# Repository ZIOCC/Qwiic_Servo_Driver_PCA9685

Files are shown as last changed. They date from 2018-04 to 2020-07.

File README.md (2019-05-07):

# Qwiic 16 Servo Driver (PCA9685)

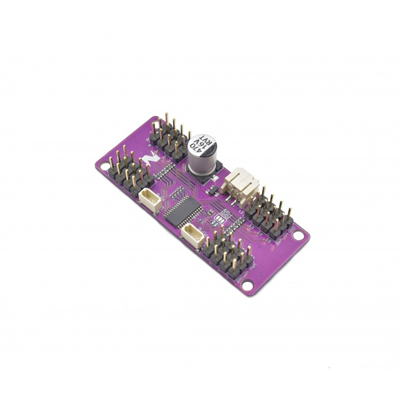
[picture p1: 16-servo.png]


> This product can be available for purchase [here](https://www.smart-prototyping.com/Zio-16-Servo-Controller.html).

#### Description

With the Zio 16-Channel 12 bit PWM controller, using the PCA9685 from NXP Semiconductors, you can control up to 16 servos or other PWM-controllable components using I2C.

Each output can be off or on (no PWM control), or set any channel to its own PWM frequency and duty cycle. The PCA9685 operates with a supply voltage range of 2.3v to 5.5v and both the inputs and outputs are 5.5v tolerant. Servos can be connected directly to output pins (up to 25 mA, 5.5v) or controlled with external drivers for more power-hungry applications. 

The board comes equipped with two Qwiic connectors to enable easy daisy-chaining. Need even more channels to control something like a hexapod robot? Quickly and easily connect another servo controller with the additional Qwiic connector and 6 solder-jumper configurable address bits. That means you can have up to 62 of these boards operating on the same I2C bus. You can also configure the boards to recognize group addresses, so that multiple boards can be controlled in parallel with a single command.

This is a derivative of Adafruit’s 16-Channel 12-bit PWM/Servo Driver - I2C interface - PCA9685, with the main difference being the addition of the Qwiic connectors. If you want to make Qwiic a regular part of your hardware hacking/making toolkit (we can’t image why you wouldn’t), this is the Servo Driver for you.

#### Specification

* 62 possible I2C addresses
* Weight: 8.0g (0.278oz)
* Dimension: 59.5x25.2 mm
* IC: PCA9685
* I2C address: 0x40-0x7F (default: 0x40)

#### Links

* [PCA9685 datasheet](https://www.smart-prototyping.com/image/data/NOA-RnD/101896%2016%20Servo%20Controller/PCA9685.pdf)
* [Adafruit PWM Servo Driver Library](https://github.com/adafruit/Adafruit-PWM-Servo-Driver-Library)
* [Example Code](https://www.smart-prototyping.com/image/data/NOA-RnD/101896%2016%20Servo%20Controller/2_servos.ino0)
* [Eagle files](https://github.com/ZIOCC/Qwiic_Servo_Driver_PCA9685)

Connections for Example Code, connecting two servos to the servo driver board. 



> ###### About Zio
> Zio is a new line of open sourced, compact, and grid layout boards, fully integrated for Arduino and Qwiic ecosystem. Designed ideally for wearables, robotics, small-space limitations or other on the go projects. Check out other awesome Zio products [here](https://www.smart-prototyping.com/Zio).

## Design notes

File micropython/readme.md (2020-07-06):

#### Usage
This driver board can control up to 16 servos via I2C. It is highly recommended to use extenal power source for the driver board, the I2C don't have enough current to drive servos.  

#### Demo code:
In this demo I connected the servo to the channel number 11, so the ser.position() first arguement is 11. 1000 us = 1ms
```  
from machine import I2C, Pin
import servo

i2c = I2C(2)
ser = servo.Servos(i2c)
while True:

    ser.position(11,us=1500) # 11 is your servo channel, us is servo position, usually the value is from 0.5ms to 2.5ms
    pyb.delay(1000)
    ser.position(11, us=2000)
    pyb.delay(1000)

```  

#### Note:
You will need to copy pca9685.py and servo.py file to your micropython board.
servo position and us relations(normally):
us value | servo position |
 ---- | -----
500 us  | 0 degree
1000 us | 45 degree
1500 us | 90 degree
2000 us | 135 degree
2500 us | 180 degree

#### Product link:
[Zio 16 Servo Controller (Qwiic)](https://www.smart-prototyping.com/Zio-16-Servo-Controller.html)

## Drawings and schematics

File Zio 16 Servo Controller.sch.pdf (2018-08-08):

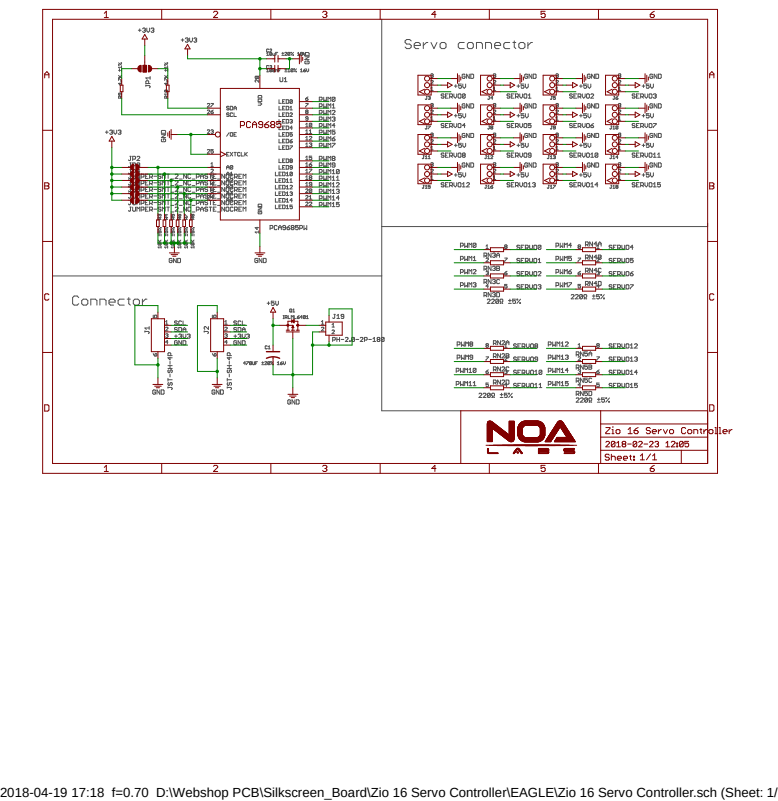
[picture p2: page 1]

2018-04-19 17:18 f=0.70 D:\Webshop PCB\Silkscreen_Board\Zio 16 Servo Controller\EAGLE\Zio 16 Servo Controller.sch (Sheet: 1/1)

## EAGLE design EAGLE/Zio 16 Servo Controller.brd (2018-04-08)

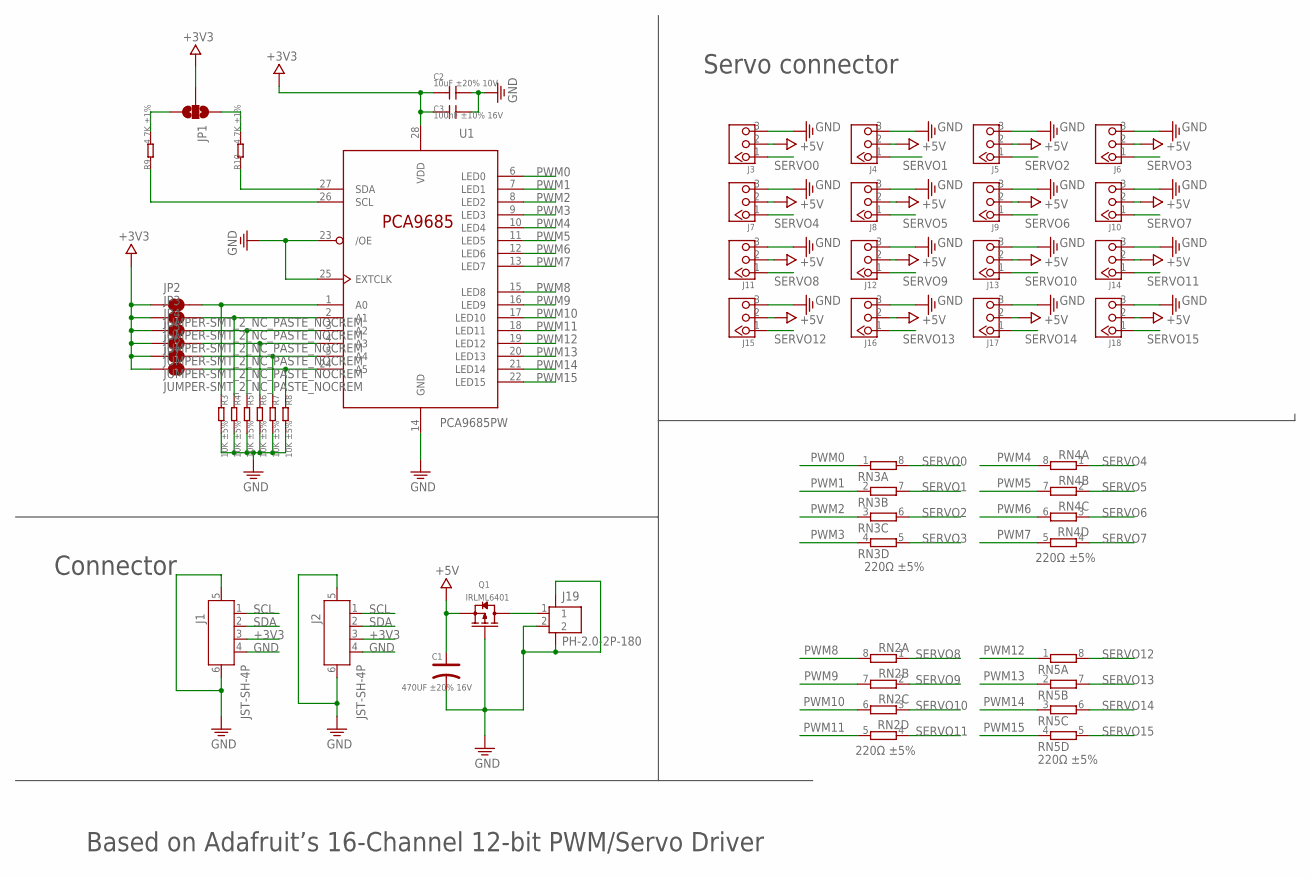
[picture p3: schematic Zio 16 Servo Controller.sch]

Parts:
C1: 470UF ±20% 16V; ELECTRO-SMD-E-7.8MM
C2: 10uF ±20% 10V; 0402
C3: 100nF ±10% 16V; 0402
J1, J2: JST-SH-4P; JST-SH-4P-90
J3, J4, J5, J6, J7, J8, J9, J10, J11, J12, J13, J14, J15, J16, J17, J18: HEADER-3P-2.54; 3P-2.54
J19: PH-2.0-2P-180; PH2.0_2P_180
JP1: JUMPER-SMT_3_2-NC_PASTE_NOCREM; SMT-JUMPER_3_2-NC_PASTE_SILK_NOCREM
JP2, JP3, JP4, JP5, JP6, JP7: JUMPER-SMT_2_NC_PASTE_NOCREM; SMT-JUMPER_2_NC_PASTE_SILK_NOCREM
Q1: IRLML6401; SOT23
R3, R4, R5, R6, R7, R8: 10K ±5%; 0402
R9, R10: 4.7K ±1%; 0402
RN2, RN3, RN4, RN5: 220Ω ±5%; RESISTOR-DIL_0603-ARV
U1: PCA9685PW; TSSOP28

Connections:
+3V3: C2.1, C3.1, J1.3, J2.3, JP1.2, JP2.1, JP3.1, JP4.1, JP5.1, JP6.1, JP7.1, U1.28 (VDD)
+5V: C1.+, J3.2, J4.2, J5.2, J6.2, J7.2, J8.2, J9.2, J10.2, J11.2, J12.2, J13.2, J14.2, J15.2, J16.2, J17.2, J18.2, Q1.2 (S)
GND: C1.-, C2.2, C3.2, J1.4, J1.5, J1.6, J2.4, J2.5, J2.6, J3.3, J4.3, J5.3, J6.3, J7.3, J8.3, J9.3, J10.3, J11.3, J12.3, J13.3, J14.3, J15.3, J16.3, J17.3, J18.3, J19.2, J19.3, J19.4, Q1.1 (G), R3.2, R4.2, R5.2, R6.2, R7.2, R8.2, U1.14 (GND), U1.23 (/OE), U1.25 (EXTCLK)
unnamed: JP2.2, R3.1, U1.1 (A0)
unnamed: JP3.2, R4.1, U1.2 (A1)
unnamed: JP4.2, R5.1, U1.3 (A2)
unnamed: JP5.2, R6.1, U1.4 (A3)
unnamed: JP6.2, R7.1, U1.5 (A4)
unnamed: JP7.2, R8.1, U1.24 (A5)
unnamed: J19.1, Q1.3 (D)
unnamed: JP1.3, R9.2
unnamed: JP1.1, R10.2
PWM0: RN3.1, U1.6 (LED0)
PWM1: RN3.2 (1), U1.7 (LED1)
PWM2: RN3.3 (1), U1.8 (LED2)
PWM3: RN3.4 (1), U1.9 (LED3)
PWM4: RN4.8 (2), U1.10 (LED4)
PWM5: RN4.7 (2), U1.11 (LED5)
PWM6: RN4.6 (2), U1.12 (LED6)
PWM7: RN4.5 (2), U1.13 (LED7)
PWM8: RN2.8 (2), U1.15 (LED8)
PWM9: RN2.7 (2), U1.16 (LED9)
PWM10: RN2.6 (2), U1.17 (LED10)
PWM11: RN2.5 (2), U1.18 (LED11)
PWM12: RN5.1, U1.19 (LED12)
PWM13: RN5.2 (1), U1.20 (LED13)
PWM14: RN5.3 (1), U1.21 (LED14)
PWM15: RN5.4 (1), U1.22 (LED15)
SCL: J1.1, J2.1, R9.1, U1.26 (SCL)
SDA: J1.2, J2.2, R10.1, U1.27 (SDA)
SERVO0: J3.1, RN3.8 (2)
SERVO1: J4.1, RN3.7 (2)
SERVO2: J5.1, RN3.6 (2)
SERVO3: J6.1, RN3.5 (2)
SERVO4: J7.1, RN4.1
SERVO5: J8.1, RN4.2 (1)
SERVO6: J9.1, RN4.3 (1)
SERVO7: J10.1, RN4.4 (1)
SERVO8: J11.1, RN2.1
SERVO9: J12.1, RN2.2 (1)
SERVO10: J13.1, RN2.3 (1)
SERVO11: J14.1, RN2.4 (1)
SERVO12: J15.1, RN5.8 (2)
SERVO13: J16.1, RN5.7 (2)
SERVO14: J17.1, RN5.6 (2)
SERVO15: J18.1, RN5.5 (2)

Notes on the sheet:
Servo connector
Connector
Based on Adafruit’s 16-Channel 12-bit PWM/Servo Driver

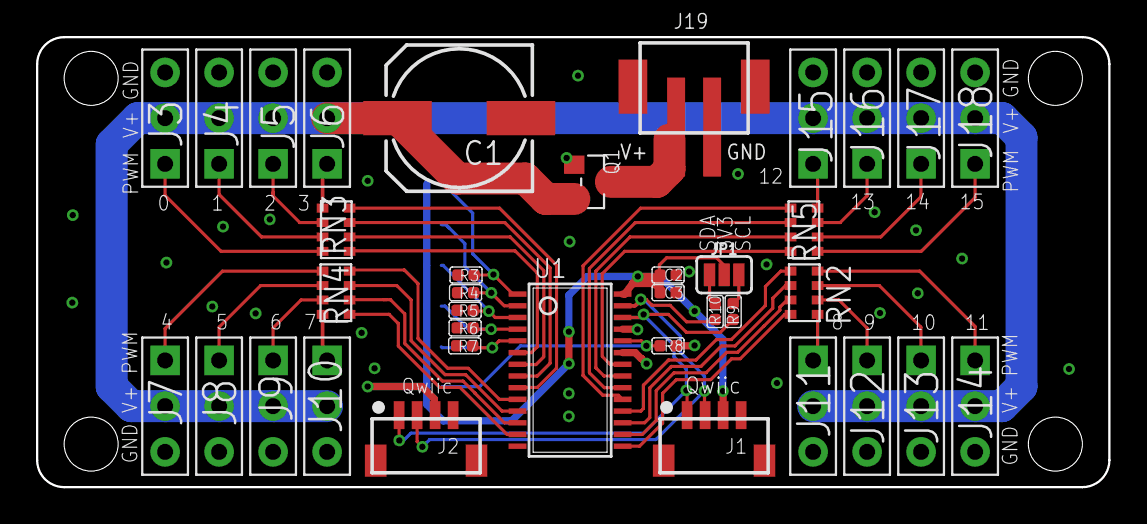
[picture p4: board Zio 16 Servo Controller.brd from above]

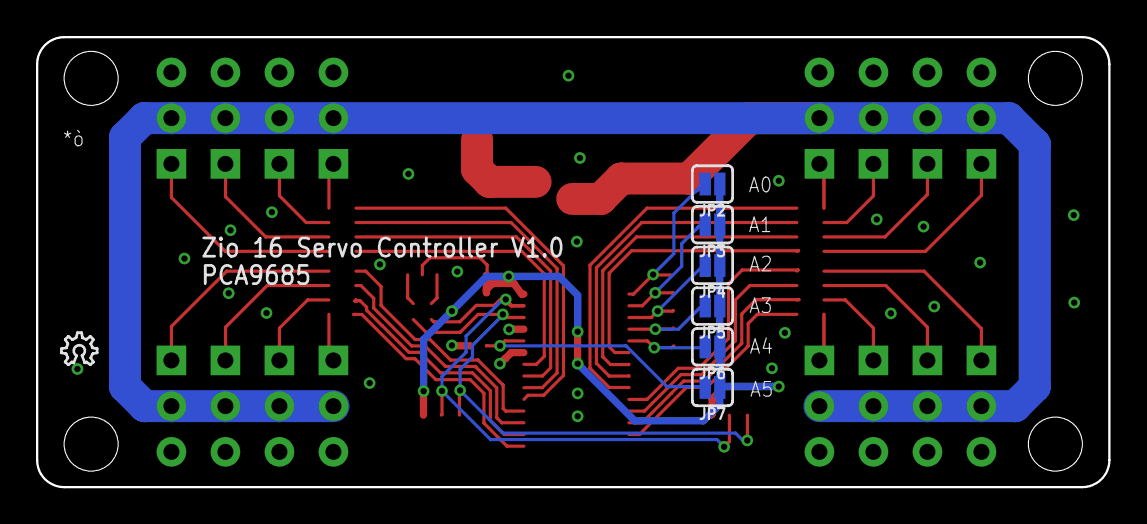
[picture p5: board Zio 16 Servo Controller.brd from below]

Board: 2 copper layers, 59.6 x 25.0 mm, 46 parts (8 on the bottom side), 46 nets.

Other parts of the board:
E$4: 7MM
LOGO1: LOGO-OSHW-6MILX0070-NT; OSHW_6X70_NOTEXT
U$21: 6MM

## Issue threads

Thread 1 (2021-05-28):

What type is the 2-pin power connector?

gdavids57, 2021-05-28:
I need to make a mating cable to supply power but can't identify the connector type.

hpaulsen, 2021-06-18:
I had the same question. Looks like jst-ph-2.0, according to the schematic.

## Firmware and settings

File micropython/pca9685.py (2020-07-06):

import ustruct
import time


class PCA9685:
    def __init__(self, i2c, address=0x40):
        self.i2c = i2c
        self.address = address
        self.reset()

    def _write(self, address, value):
        self.i2c.writeto_mem(self.address, address, bytearray([value]))

    def _read(self, address):
        return self.i2c.readfrom_mem(self.address, address, 1)[0]

    def reset(self):
        self._write(0x00, 0x00) # Mode1

    def freq(self, freq=None):
        if freq is None:
            return int(25000000.0 / 4096 / (self._read(0xfe) - 0.5))
        prescale = int(25000000.0 / 4096.0 / freq + 0.5)
        old_mode = self._read(0x00) # Mode 1
        self._write(0x00, (old_mode & 0x7F) | 0x10) # Mode 1, sleep
        self._write(0xfe, prescale) # Prescale
        self._write(0x00, old_mode) # Mode 1
        time.sleep_us(5)
        self._write(0x00, old_mode | 0xa1) # Mode 1, autoincrement on

    # pwm, when on and off is empty, return current setting, or send on off data to register
    def pwm(self, index, on=None, off=None):
        if on is None or off is None:
            data = self.i2c.readfrom_mem(self.address, 0x06 + 4 * index, 4)
            return ustruct.unpack('<HH', data)
        data = ustruct.pack('<HH', on, off)
        self.i2c.writeto_mem(self.address, 0x06 + 4 * index,  data)

    # 判断是否有invert，反向值操作，然后用pwm()方法发送指令
    def duty(self, index, value=None, invert=False):
        if value is None:
            pwm = self.pwm(index)
            if pwm == (0, 4096):
                value = 0
            elif pwm == (4096, 0):
                value = 4095
            value = pwm[1]
            if invert:
                value = 4095 - value
            return value
        if not 0 <= value <= 4095:
            raise ValueError("Out of range")
        if invert:
            value = 4095 - value
        if value == 0:
            self.pwm(index, 0, 4096)
        elif value == 4095:
            self.pwm(index, 4096, 0)
        else:
            self.pwm(index, 0, value)

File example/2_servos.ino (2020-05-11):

/*************************************************** 
  This is an example for our Adafruit 16-channel PWM & Servo driver
  Servo test - this will drive 16 servos, one after the other

  Pick one up today in the adafruit shop!
  ------> http://www.adafruit.com/products/815

  These displays use I2C to communicate, 2 pins are required to  
  interface. For Arduino UNOs, thats SCL -> Analog 5, SDA -> Analog 4

  Adafruit invests time and resources providing this open source code, 
  please support Adafruit and open-source hardware by purchasing 
  products from Adafruit!

  Written by Limor Fried/Ladyada for Adafruit Industries.  
  BSD license, all text above must be included in any redistribution
 ****************************************************/

#include <Wire.h>
#include <Adafruit_PWMServoDriver.h>

// called this way, it uses the default address 0x40
Adafruit_PWMServoDriver pwm = Adafruit_PWMServoDriver();
// you can also call it with a different address you want
//Adafruit_PWMServoDriver pwm = Adafruit_PWMServoDriver(0x41);

// Depending on your servo make, the pulse width min and max may vary, you 
// want these to be as small/large as possible without hitting the hard stop
// for max range. You'll have to tweak them as necessary to match the servos you
// have!
#define SERVOMIN  150 // this is the 'minimum' pulse length count (out of 4096)
#define SERVOMAX  600 // this is the 'maximum' pulse length count (out of 4096)

// our servo # counter
uint8_t servonum = 0;

void setup() {
  Serial.begin(9600);
  Serial.println("16 channel Servo test!");

  pwm.begin();
  
  pwm.setPWMFreq(60);  // Analog servos run at ~60 Hz updates

  yield();
}

// you can use this function if you'd like to set the pulse length in seconds
// e.g. setServoPulse(0, 0.001) is a ~1 millisecond pulse width. its not precise!
void setServoPulse(uint8_t n, double pulse) {
  double pulselength;
  
  pulselength = 1000000;   // 1,000,000 us per second
  pulselength /= 60;   // 60 Hz
  Serial.print(pulselength); Serial.println(" us per period"); 
  pulselength /= 4096;  // 12 bits of resolution
  Serial.print(pulselength); Serial.println(" us per bit"); 
  pulse *= 1000;
  pulse /= pulselength;
  Serial.println(pulse);
  pwm.setPWM(n, 0, pulse);
}

void loop() {
  // Drive each servo one at a time
  Serial.println(servonum);
  for (uint16_t pulselen = SERVOMIN; pulselen < SERVOMAX; pulselen++) {
    pwm.setPWM(servonum, 0, pulselen);
  }

  delay(500);
  for (uint16_t pulselen = SERVOMAX; pulselen > SERVOMIN; pulselen--) {
    pwm.setPWM(servonum, 0, pulselen);
  }

  delay(500);

  servonum ++;
  if (servonum > 1) servonum = 0;
}
